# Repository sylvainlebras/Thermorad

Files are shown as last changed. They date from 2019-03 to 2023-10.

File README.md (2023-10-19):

# Thermorad
Intuitive EMC tool with visual feedback
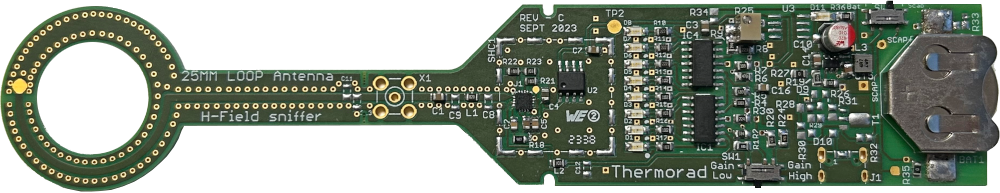
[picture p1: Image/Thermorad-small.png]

This tool is meant to be used for EMC investigation and EMC teaching, it provides a simple and quick feedback through an 8 LED indicator.

Possible use includes : 
- Locating near H-field emission sources 
- Locating near E-field emission sources (requires E Field antenna)
- Demonstrating polarisation of emitters-receivers
- Locating wifi and 4G/5G antennas on a phone
- Evaluation of perturbations carried by a cable (requires ferrite clamp)

Coming next
- Version D with Geiger like sound output
- E-Field antenna
- Small diameter H Field antenna

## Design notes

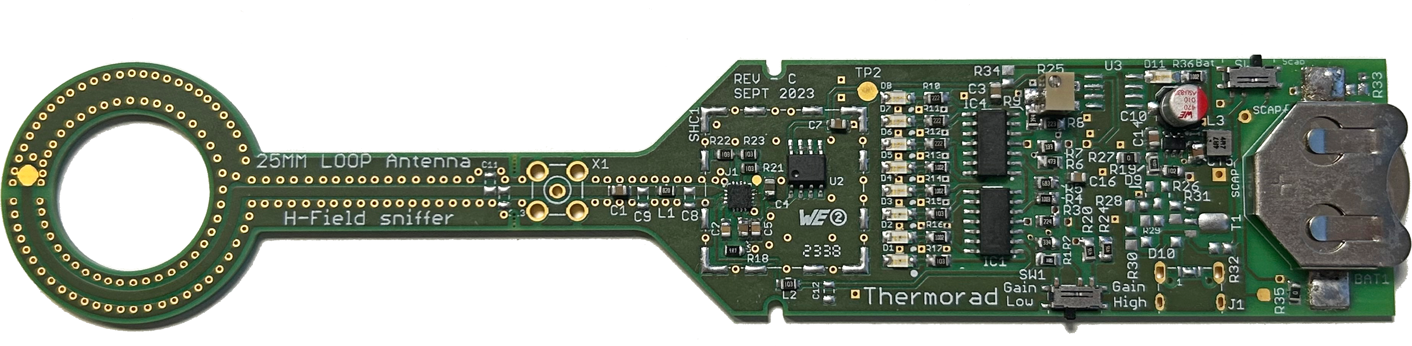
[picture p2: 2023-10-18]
Image/Thermorad-C.png

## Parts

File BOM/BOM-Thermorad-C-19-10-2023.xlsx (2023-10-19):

Parts | Qty | Value | Device | Package | Description | Manufacturer
C2, C5 | 2 | 0805/100nF/16V | 885012207045 | WCAP-CSGP_0805_REFLOW | WCAP-CSGP Ceramic Capacitors | Wurth-Elektronik / Generic
C14, C15 | 2 | 0805/10µF/10V | 885012207026 | C0805 | CAPACITOR, European symbol | Wurth-Elektronik / Generic
C7, C16 | 2 | 0805/1µF/10V | 885012207051 | WCAP-CSGP_0805_REFLOW | WCAP-CSGP Ceramic Capacitors | Wurth-Elektronik / Generic
C6 | 1 | 0805/1µF/16V | 885012207051 | WCAP-CSGP_0805_REFLOW | WCAP-CSGP Ceramic Capacitors | Wurth-Elektronik / Generic
C3 | 1 | 0805/2.2µF/10V | 885012207024 | WCAP-CSGP_0805_REFLOW | WCAP-CSGP Ceramic Capacitors | Wurth-Elektronik / Generic
C4 | 1 | 0805/22µF/10V | 885012107011 | WCAP-CSGP_0805_REFLOW | WCAP-CSGP Ceramic Capacitors | Wurth-Elektronik / Generic
R27, R35 | 2 | 0R | R-EU_R0805 | R0805 | RESISTOR, European symbol | Generic
R4 | 1 | 100k | R-EU_M0805 | M0805 | RESISTOR, European symbol | Generic
R25 | 1 | 100k/TC33X-2-104G | R-TRIMM3224X | RTRIM3224X | Trimm resistor | Bourns / Generic
C10 | 1 | 100µF/6.3V/865080142007 | WCAP-ASLI_5X5.5(DXL) | 3X1.6X1.4(BXCXA) | WCAP-ASLI Aluminum Electrolytic Capacitors | Wurth-Elektronik
R32 | 1 | 10R/DNP | R-EU_R0805 | R0805 | RESISTOR, European symbol
R13, R14, R15, R16, R17, R21, R22, R23, R36 | 9 | 10k | R-EU_M0805 | M0805 | RESISTOR, European symbol | Generic
R28 | 1 | 10k/DNP | R-EU_R0805 | R0805 | RESISTOR, European symbol
D2, D3 | 2 | 150120AS75000 | WL-SMCW-150120GS75000-G | 1206 | SMD mono-color Chip LED | Wurth-Elektronik
D6, D7, D8, D11 | 4 | 150120BS75000 | WL-SMCW-150120GS75000-G | 1206 | SMD mono-color Chip LED | Wurth-Elektronik
D4, D5 | 2 | 150120GS75000 | WL-SMCW-150120GS75000-G | 1206 | SMD mono-color Chip LED | Wurth-Elektronik
D1 | 1 | 150120RS75000 | WL-SMCW-150120GS75000-G | 1206 | SMD mono-color Chip LED | Wurth-Elektronik
R31 | 1 | 1K/DNP | R-EU_R0805 | R0805 | RESISTOR, European symbol
R1 | 1 | 1M8 | R-EU_M0805 | M0805 | RESISTOR, European symbol | Generic
R26 | 1 | 1k | R-EU_R0805 | R0805 | RESISTOR, European symbol | Generic
R3 | 1 | 220k | R-EU_M0805 | M0805 | RESISTOR, European symbol | Generic
R29 | 1 | 22R/DNP | R-EU_R0805 | R0805 | RESISTOR, European symbol
R8 | 1 | 22k | R-EU_M0805 | M0805 | RESISTOR, European symbol | Generic
R10, R11, R12 | 3 | 2k2 | R-EU_M0805 | M0805 | RESISTOR, European symbol | Generic
L3 | 1 | 74438336047 | WE-MAPI_3015/3020 | WE-MAPI_3015/3020 | SMD Metal Alloy Power Inductor | Wurth-Elektronik
R2 | 1 | 330k | R-EU_M0805 | M0805 | RESISTOR, European symbol | Generic
R7 | 1 | 33k | R-EU_M0805 | M0805 | RESISTOR, European symbol | Generic
R9 | 1 | 390k | R-EU_M0805 | M0805 | RESISTOR, European symbol | Generic
SW1, SW2 | 2 | 450404015514 | 450404015514 | 450404015514 | WS-SLSU | Wurth-Elektronik
R6 | 1 | 47k | R-EU_M0805 | M0805 | RESISTOR, European symbol | Generic
R20, R24 | 2 | 4M7 | R-EU_M0805 | M0805 | RESISTOR, European symbol | Generic
R18 | 1 | 4R7 | R-EU_M0805 | M0805 | RESISTOR, European symbol | Generic
R30 | 1 | 680/DNP | R-EU_R0805 | R0805 | RESISTOR, European symbol
R5 | 1 | 68k | R-EU_M0805 | M0805 | RESISTOR, European symbol | Generic
BAT1 | 1 | 79523141 | WA-BCMC_SMT_79523141 | 79523141 | Battery Holder WA-BCMC | Wurth-Elektronik
BAT2 | 1 | 79523141/DNP | WA-BCMC_SMT_79523141 | 79523141 | Battery Holder WA-BCMC
R19 | 1 | 9.1k | R-EU_R0805 | R0805 | RESISTOR, European symbol | Generic
U1 | 1 | ADL5910 | ADL5910 | LFCSP-16 |  | Analog Devices
C1 | 1 | 0805/1µF | 885012207051 | WCAP-CSGP_0805_REFLOW | WCAP-CSGP Ceramic Capacitors | Wurth-Elektronik / Generic
J1 | 1 | DNP | 629105150521 | 629105150521 | WR-COM_USB_Micro Type B_Horizontal_SMT ;
T1 | 1 | DNP | BF622-NPN-SOT89-BCE | SOT89-BCE | NPN Transistror
D10 | 1 | DNP | DIODE-SOD123 | SOD123 | DIODE
R33, R34 | 2 | DNP | R-EU_R0805 | R0805 | RESISTOR, European symbol
C8, C12 | 2 | DNP | WCAP-CSGP_0805-REFLOW | WCAP-CSGP_0805_REFLOW | WCAP-CSGP Ceramic Capacitors
C9 | 1 | DNP/!RES/0805/82R | WCAP-CSGP_0805-REFLOW | WCAP-CSGP_0805_REFLOW | WCAP-CSGP Ceramic Capacitors
C11, C13 | 2 | DNP/1N4148 | WCAP-CSGP_0805-REFLOW | WCAP-CSGP_0805_REFLOW | WCAP-CSGP Ceramic Capacitors
SHC1 | 1 | DNP/36103205S | WE-SHC_36103205S | WE-SHC_36103205S | Shielding Cabinet
X1 | 1 | DNP/BU-SMA-V | BU-SMA-V | BU-SMA-V | FEMALE SMA CONNECTOR
U2 | 1 | LM2936M-3.3 | LM2936M-3.3 | SO08 | Ultra-Low Quiescent Current LDO Voltage Regulator | Texas Instruments
U3 | 1 | LM2936M-5.0/DNP | LM2936M-5.0 | SO08 | Ultra-Low Quiescent Current LDO Voltage Regulator
IC1, IC4 | 2 | LM324D | Many more like AD8644R | SO14 | Single and Quad 18 V Operational Amplifiers | Generic
D9 | 1 | LM431-SACM3X/DNP | LM431-SACM3X | SOT23
L2 | 1 | RES/0805/10k |  | 805 | WE-CBF SMD EMI Suppression Ferrite Bead | Generic
L1 | 1 | RES/0805/82R/5% |  | 805 | SMD Wire Wound Ceramic Inductor | Generic
SCAP2 | 1 | TESTPOINT-GROS | TESTPOINT-GROS | TESTPOINT-GROS
TP3 | 1 | TPB1,27 | TPB1,27 | B1,27 | Test pad
TP1, TP2 | 2 | TPB2,54 | TPB2,54 | B2,54 | Test pad
IC2 | 1 | TPS61070DDC | TPS61070DDC | TSOT23-6_DDC | 90% EFFICIENT SYNCHRONOUS BOOST CONVERTER WITH 600-mA SWITCH | Texas Instruments

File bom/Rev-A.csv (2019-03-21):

Part | Value | Device | Package | Description
BAT1 | 79523141 | WA-BCMC_SMT_79523141 | 79523141 | Battery Holder WA-BCMC
BAT2 | 79523141 | WA-BCMC_SMT_79523141 | 79523141 | Battery Holder WA-BCMC
C1 |  | WCAP-CSGP_0805-REFLOW | WCAP-CSGP_0805_REFLOW | WCAP-CSGP Ceramic Capacitors
C2 |  | WCAP-CSGP_0805-REFLOW | WCAP-CSGP_0805_REFLOW | WCAP-CSGP Ceramic Capacitors
C3 |  | WCAP-CSGP_0805-REFLOW | WCAP-CSGP_0805_REFLOW | WCAP-CSGP Ceramic Capacitors
C4 |  | WCAP-CSGP_0805-REFLOW | WCAP-CSGP_0805_REFLOW | WCAP-CSGP Ceramic Capacitors
C5 |  | WCAP-CSGP_0805-REFLOW | WCAP-CSGP_0805_REFLOW | WCAP-CSGP Ceramic Capacitors
C6 |  | WCAP-CSGP_0805-REFLOW | WCAP-CSGP_0805_REFLOW | WCAP-CSGP Ceramic Capacitors
C7 |  | WCAP-CSGP_0805-REFLOW | WCAP-CSGP_0805_REFLOW | WCAP-CSGP Ceramic Capacitors
C8 |  | WCAP-CSGP_0805-REFLOW | WCAP-CSGP_0805_REFLOW | WCAP-CSGP Ceramic Capacitors
C9 |  | WCAP-CSGP_0805-REFLOW | WCAP-CSGP_0805_REFLOW | WCAP-CSGP Ceramic Capacitors
C10 |  | WCAP-ASLI_5X5.5(DXL) | 3X1.6X1.4(BXCXA) | WCAP-ASLI Aluminum Electrolytic Capacitors
C11 |  | WCAP-CSGP_0805-REFLOW | WCAP-CSGP_0805_REFLOW | WCAP-CSGP Ceramic Capacitors
C12 |  | WCAP-CSGP_0805-REFLOW | WCAP-CSGP_0805_REFLOW | WCAP-CSGP Ceramic Capacitors
C13 |  | WCAP-CSGP_0805-REFLOW | WCAP-CSGP_0805_REFLOW | WCAP-CSGP Ceramic Capacitors
D1 | 150120GS75000 | WL-SMCW-150120GS75000-G | 1206 | SMD mono-color Chip LED
D2 | 150120GS75000 | WL-SMCW-150120GS75000-G | 1206 | SMD mono-color Chip LED
D3 | 150120GS75000 | WL-SMCW-150120GS75000-G | 1206 | SMD mono-color Chip LED
D4 | 150120GS75000 | WL-SMCW-150120GS75000-G | 1206 | SMD mono-color Chip LED
D5 | 150120GS75000 | WL-SMCW-150120GS75000-G | 1206 | SMD mono-color Chip LED
D6 | 150120GS75000 | WL-SMCW-150120GS75000-G | 1206 | SMD mono-color Chip LED
D7 | 150120GS75000 | WL-SMCW-150120GS75000-G | 1206 | SMD mono-color Chip LED
D8 | 150120GS75000 | WL-SMCW-150120GS75000-G | 1206 | SMD mono-color Chip LED
IC1 | AD8644R | AD8644R | SO14 | Single and Quad 18 V Operational Amplifiers
IC4 | AD8644R | AD8644R | SO14 | Single and Quad 18 V Operational Amplifiers
L1 |  | WE-KI_0805A | WE-KI_0805A | SMD Wire Wound Ceramic Inductor
L2 |  | WE-CBF_0805_74279209_WB_HS | WE-CBF_0805(W=3.0) | WE-CBF SMD EMI Suppression Ferrite Bead
R1 | 3M3 | R-EU_M0805 | M0805 | RESISTOR, European symbol
R2 | TBD | R-EU_M0805 | M0805 | RESISTOR, European symbol
R3 | TBD | R-EU_M0805 | M0805 | RESISTOR, European symbol
R4 | TBD | R-EU_M0805 | M0805 | RESISTOR, European symbol
R5 | TBD | R-EU_M0805 | M0805 | RESISTOR, European symbol
R6 | TBD | R-EU_M0805 | M0805 | RESISTOR, European symbol
R7 | TBD | R-EU_M0805 | M0805 | RESISTOR, European symbol
R8 | TBD | R-EU_M0805 | M0805 | RESISTOR, European symbol
R9 | 47k | R-EU_M0805 | M0805 | RESISTOR, European symbol
R10 | 10k | R-EU_M0805 | M0805 | RESISTOR, European symbol
R11 | 10k | R-EU_M0805 | M0805 | RESISTOR, European symbol
R12 | 10k | R-EU_M0805 | M0805 | RESISTOR, European symbol
R13 | 10k | R-EU_M0805 | M0805 | RESISTOR, European symbol
R14 | 10k | R-EU_M0805 | M0805 | RESISTOR, European symbol
R15 | 10k | R-EU_M0805 | M0805 | RESISTOR, European symbol
R16 | 10k | R-EU_M0805 | M0805 | RESISTOR, European symbol
R17 | 10k | R-EU_M0805 | M0805 | RESISTOR, European symbol
R18 |  | R-EU_R0603 | R0603 | RESISTOR, European symbol
R19 | 100k | POTENTIOMETER_PT_SPIN | PT-SPIN | Potentiometer
R20 |  | R-EU_M0805 | M0805 | RESISTOR, European symbol
R21 |  | R-EU_R0603 | R0603 | RESISTOR, European symbol
R22 |  | R-EU_R0603 | R0603 | RESISTOR, European symbol
R23 |  | R-EU_R0603 | R0603 | RESISTOR, European symbol
SHC1 | 36103205S | WE-SHC_36103205S | WE-SHC_36103205S | Shielding Cabinet
SW1 | 450404015514 | 450404015514 | 450404015514 | WS-SLSU
SW2 | 450404015514 | 450404015514 | 450404015514 | WS-SLSU
TP1 | TPB2,54 | TPB2,54 | B2,54 | Test pad
TP2 | TPB2,54 | TPB2,54 | B2,54 | Test pad
TP3 | TPB1,27 | TPB1,27 | B1,27 | Test pad
U1 | ADL5910 | ADL5910 | LFCSP-16
U2 | LM2936M-3.3 | LM2936M-3.3 | SO08 | Ultra-Low Quiescent Current LDO Voltage Regulator
U3 | LM2936M-5.0 | LM2936M-5.0 | SO08 | Ultra-Low Quiescent Current LDO Voltage Regulator
X1 | BU-SMA-V | BU-SMA-V | BU-SMA-V | FEMALE SMA CONNECTOR

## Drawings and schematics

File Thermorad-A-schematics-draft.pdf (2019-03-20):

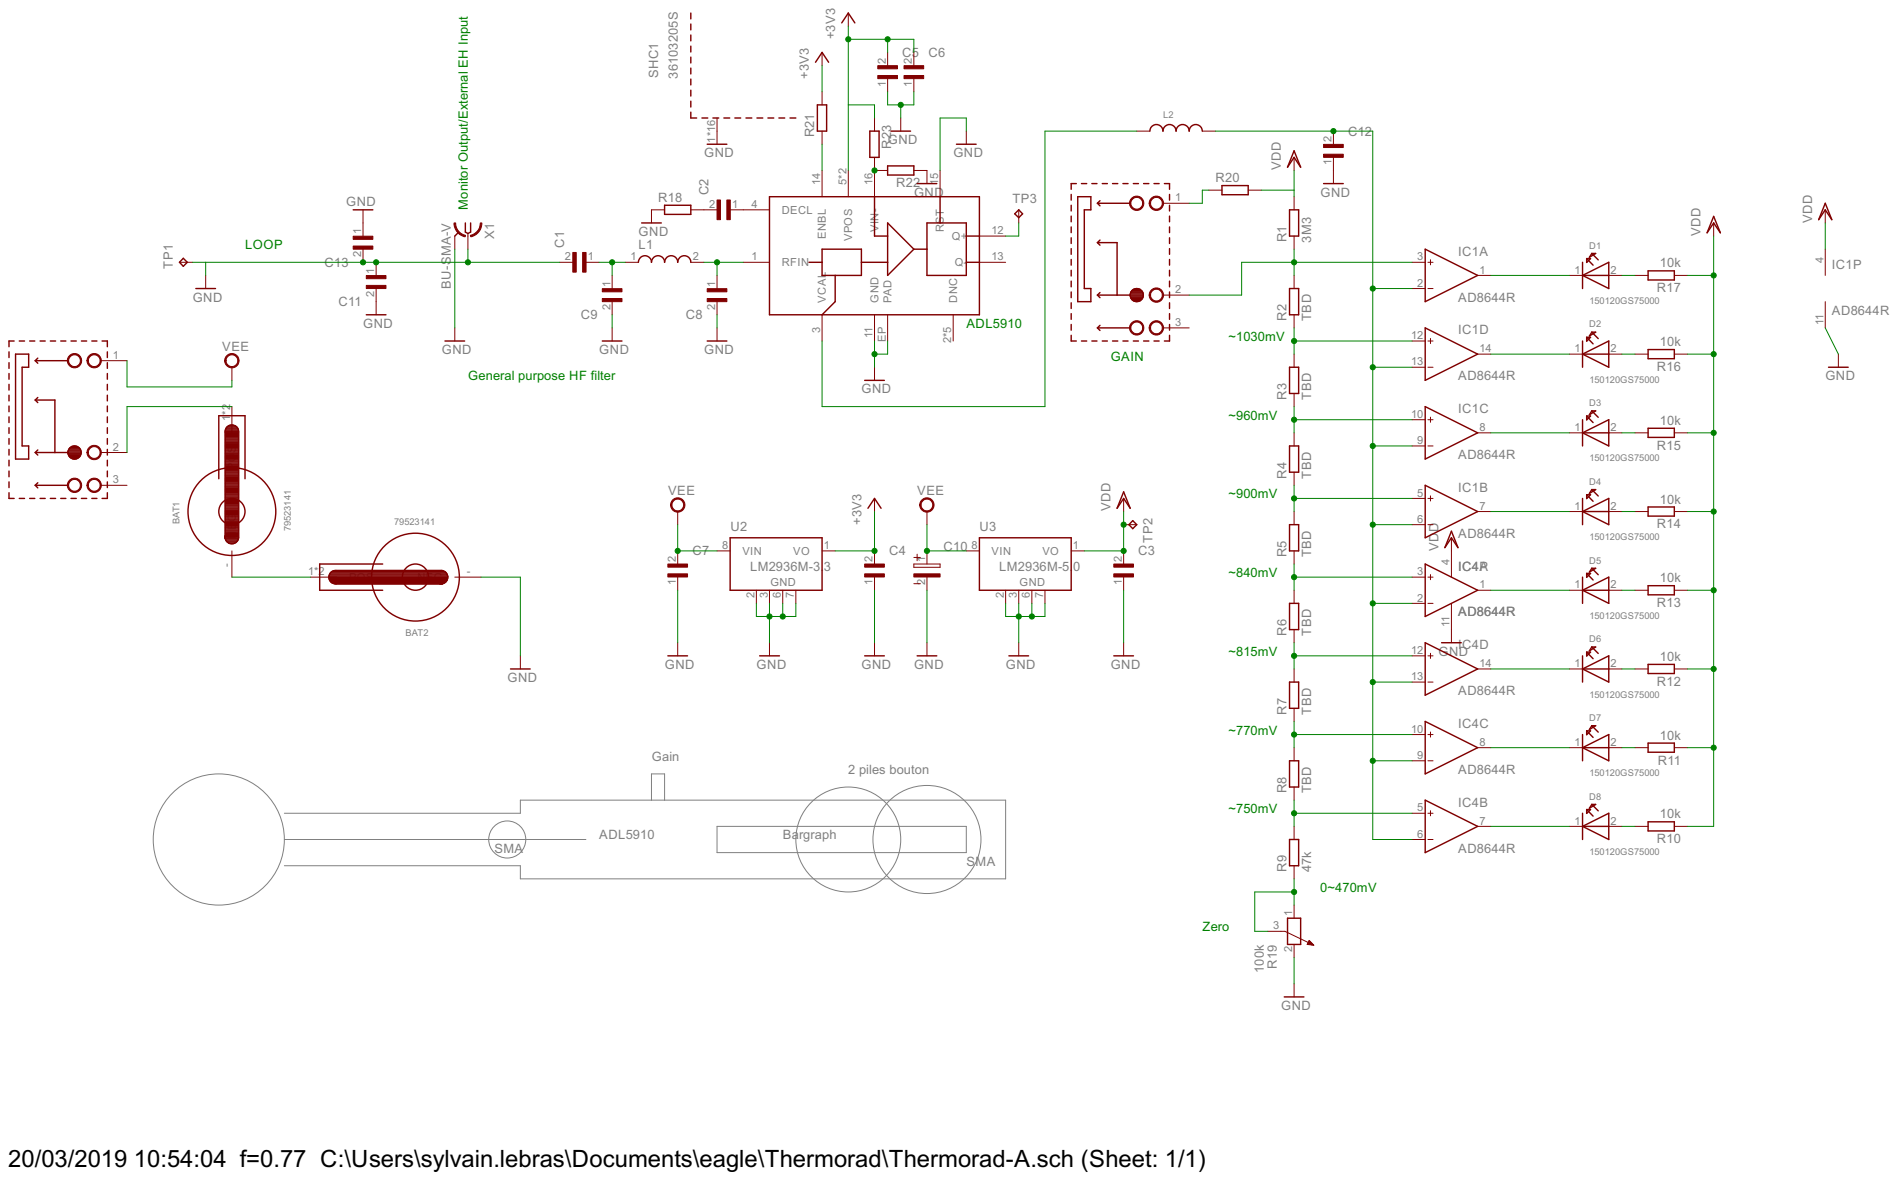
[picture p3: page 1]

Monitor Output/External EH Input

3M3 TBD TBD TBD TBD TBD TBD TBD 47k GND

General purpose HF filter

2 piles bouton Bargraph Gain

20/03/2019 10:54:04 f=0.77 C:\Users\sylvain.lebras\Documents\eagle\Thermorad\Thermorad-A.sch (Sheet: 1/1)

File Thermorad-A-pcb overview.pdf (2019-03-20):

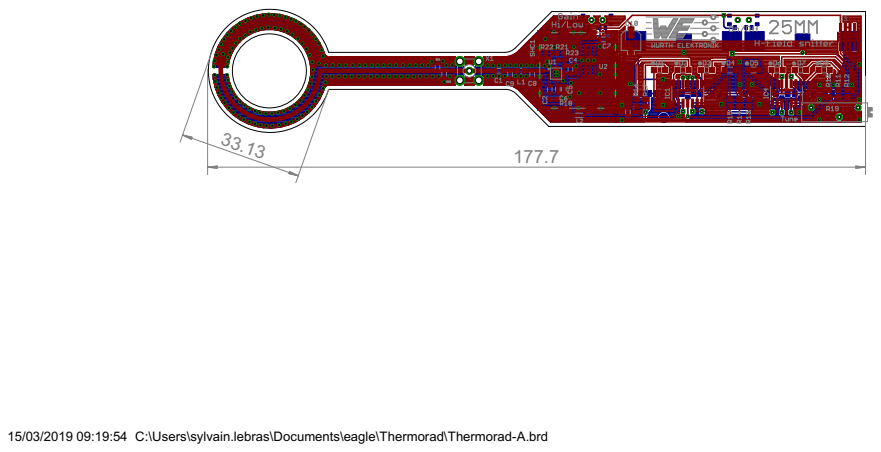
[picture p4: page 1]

15/03/2019 09:19:54 C:\Users\sylvain.lebras\Documents\eagle\Thermorad\Thermorad-A.brd

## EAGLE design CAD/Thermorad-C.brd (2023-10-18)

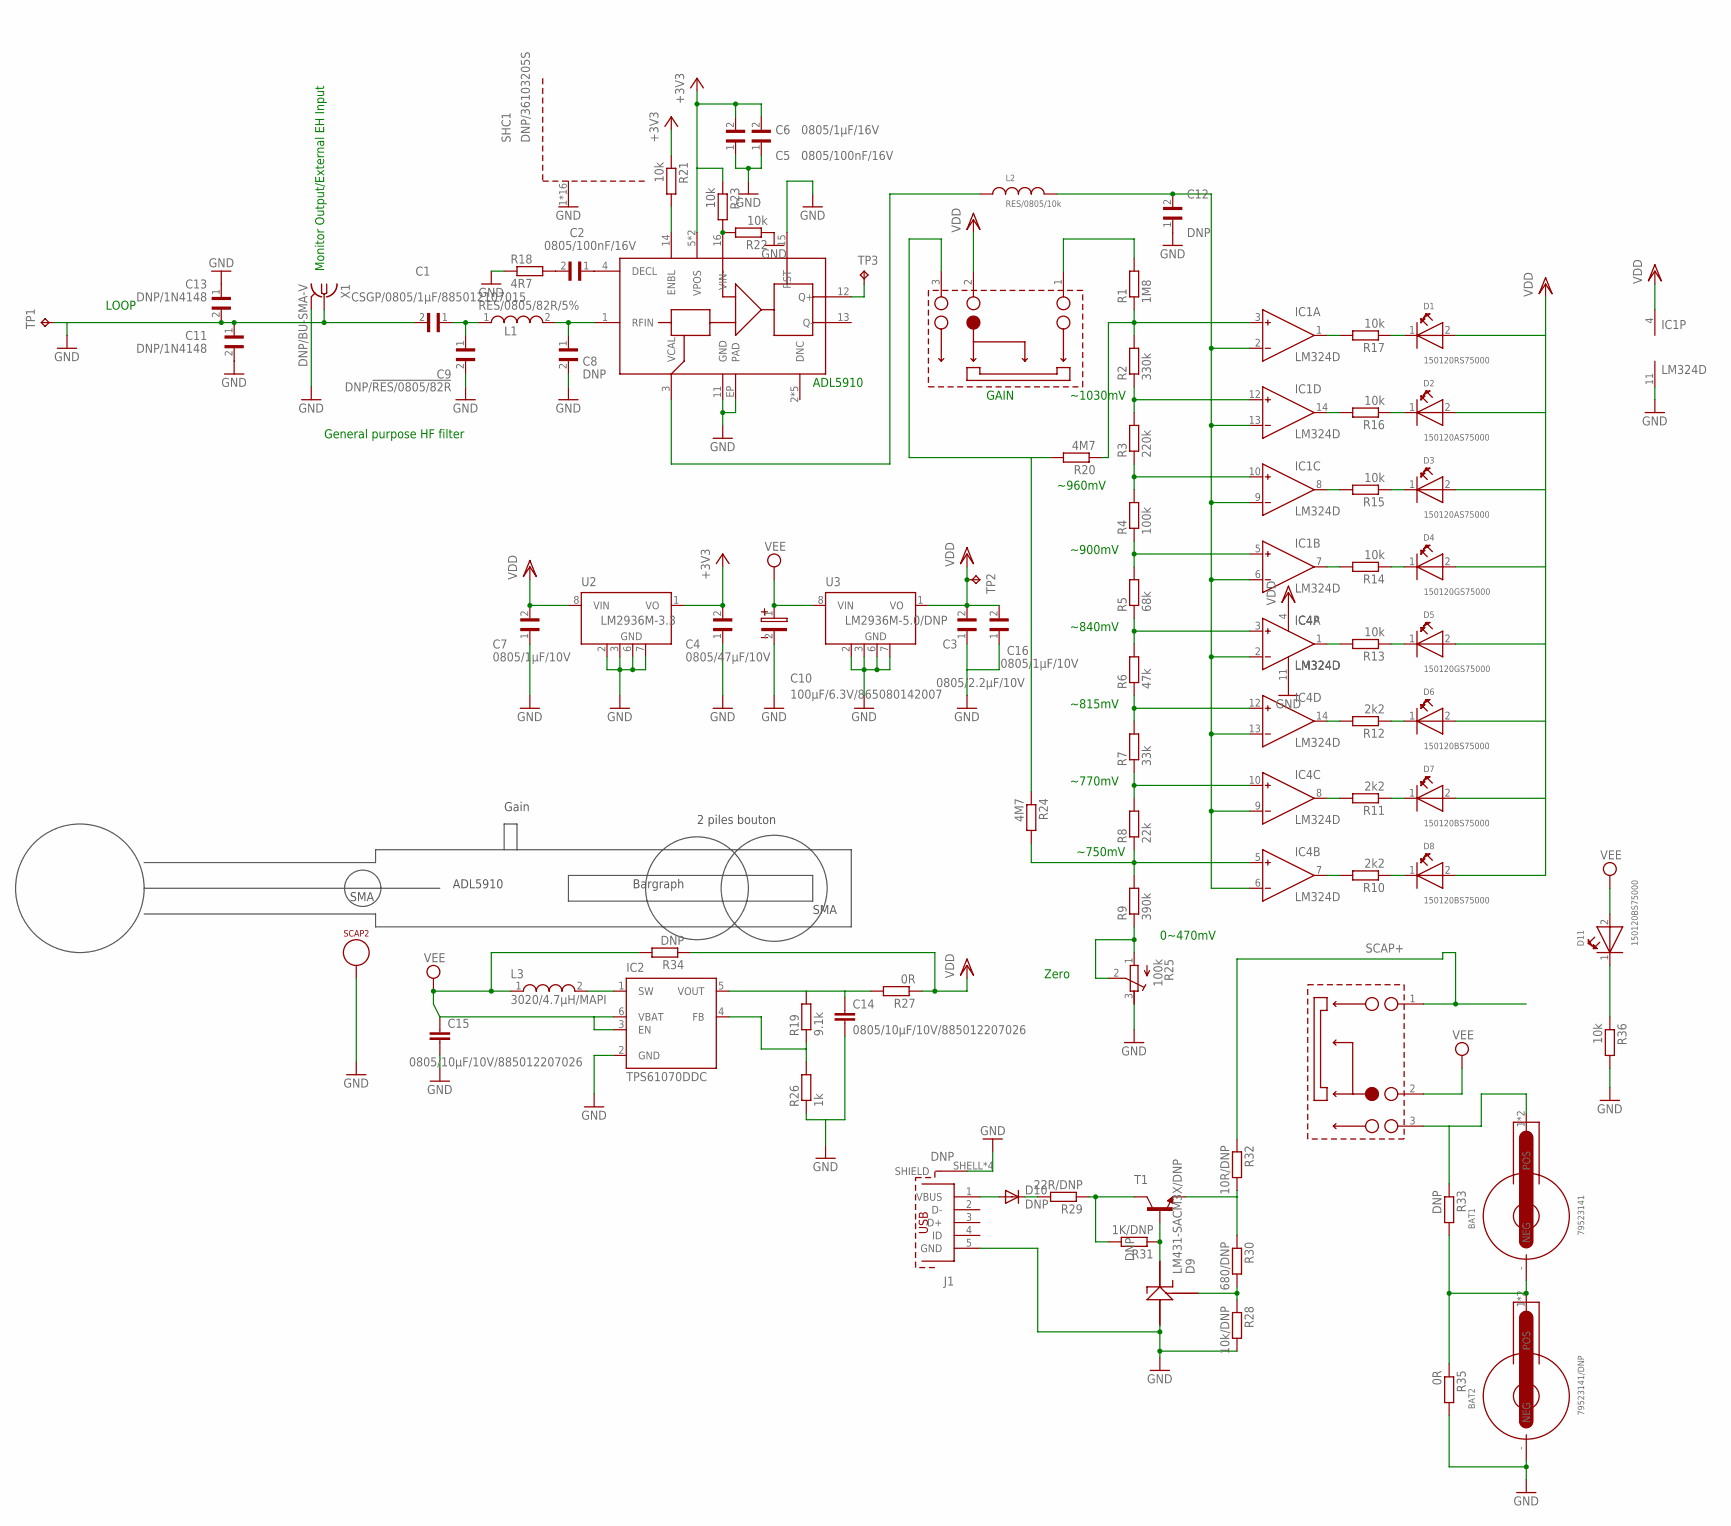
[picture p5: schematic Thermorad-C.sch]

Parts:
BAT1: 79523141
BAT2: 79523141/DNP; 79523141
C1: CSGP/0805/1µF/885012107015; WCAP-CSGP_0805_REFLOW
C2, C5: 0805/100nF/16V; WCAP-CSGP_0805_REFLOW
C3: 0805/2.2µF/10V; WCAP-CSGP_0805_REFLOW
C4: 0805/47µF/10V; WCAP-CSGP_0805_REFLOW
C6: 0805/1µF/16V; WCAP-CSGP_0805_REFLOW
C7, C16: 0805/1µF/10V; WCAP-CSGP_0805_REFLOW
C8, C12: DNP; WCAP-CSGP_0805_REFLOW
C9: DNP/!RES/0805/82R; WCAP-CSGP_0805_REFLOW
C10: 100µF/6.3V/865080142007; 3X1.6X1.4(BXCXA)
C11, C13: DNP/1N4148; WCAP-CSGP_0805_REFLOW
C14, C15: 0805/10µF/10V/885012207026; C0805
D1: 150120RS75000; 1206
D2, D3: 150120AS75000; 1206
D4, D5: 150120GS75000; 1206
D6, D7, D8, D11: 150120BS75000; 1206
D9: LM431-SACM3X/DNP; SOT23
D10: DNP; SOD123
IC1: LM324D; SO14; MPN AD8644ARZ
IC2: TPS61070DDC; TSOT23-6_DDC
IC4: LM324D; SO14
J1: DNP; 629105150521
L1: RES/0805/82R/5%; WE-KI_0805A
L2: RES/0805/10k; WE-CBF_0805(W=3.0)
L3: 3020/4.7µH/MAPI; WE-MAPI_3015/3020
R1: 1M8; M0805
R2: 330k; M0805
R3: 220k; M0805
R4: 100k; M0805
R5: 68k; M0805
R6: 47k; M0805
R7: 33k; M0805
R8: 22k; M0805
R9: 390k; M0805
R10, R11, R12: 2k2; M0805
R13, R14, R15, R16, R17, R21, R22, R23, R36: 10k; M0805
R18: 4R7; M0805
R19: 9.1k; R0805
R20, R24: 4M7; M0805
R25: 100k; RTRIM3224X
R26: 1k; R0805
R27, R35: 0R; R0805
R28: 10k/DNP; R0805
R29: 22R/DNP; R0805
R30: 680/DNP; R0805
R31: 1K/DNP; R0805
R32: 10R/DNP; R0805
R33, R34: DNP; R0805
SCAP2: TESTPOINT-GROS
SHC1: DNP/36103205S; WE-SHC_36103205S
SW1, SW2: 450404015514
T1: DNP; SOT89-BCE
TP1, TP2: TPB2,54; B2,54
TP3: TPB1,27; B1,27
U1: ADL5910; LFCSP-16
U2: LM2936M-3.3; SO08
U3: LM2936M-5.0/DNP; SO08
X1: DNP/BU-SMA-V; BU-SMA-V

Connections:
+3V3: C4.2, C5.2, C6.2, R21.1, R23.1, U1.5 (VPOS), U1.7 (VPOS), U2.1 (VO)
GND: BAT2.- (NEG), C1.2, C3.1, C4.1, C5.1, C6.1, C7.1, C8.2, C9.2, C10.2, C11.1, C11.2, C12.1, C13.1, C13.2, C14.2, C15.2, C16.1, D9.3 (A), IC1.11 (V-), IC2.2 (GND), IC4.11 (V-), J1.5 (GND), J1.SHELL (SHIELD), J1.SHELL1 (SHIELD), J1.SHELL2 (SHIELD), J1.SHELL3 (SHIELD), R18.1, R22.1, R25.3 (A), R26.1, R28.2, R35.2, R36.2, SCAP2.1, SHC1.1, SHC1.2, SHC1.3, SHC1.4, SHC1.5, SHC1.6, SHC1.7, SHC1.8, SHC1.9, SHC1.10, SHC1.11, SHC1.12, SHC1.13, SHC1.14, SHC1.15, SHC1.16, TP1.TP, U1.11 (GND), U1.15 (RST), U1.EP (PAD), U2.2 (GND), U2.3 (GND), U2.6 (GND), U2.7 (GND), U3.2 (GND), U3.3 (GND), U3.6 (GND), U3.7 (GND), X1.1, X1.2 (GND), X1.3 (GND), X1.4 (GND), X1.5 (GND)
unnamed: IC2.1 (SW), L3.2
unnamed: IC4.10 (IN+), R7.1, R8.2
unnamed: IC4.12 (IN+), R6.1, R7.2
unnamed: IC4.3 (IN+), R5.1, R6.2
unnamed: IC1.5 (IN+), R4.1, R5.2
unnamed: IC1.10 (IN+), R3.1, R4.2
unnamed: IC1.12 (IN+), R2.1, R3.2
unnamed: IC1.3 (IN+), R1.1, R2.2, R20.1
unnamed: C1.1, C9.1, L1.1
unnamed: IC4.14 (OUT), R12.2
unnamed: C8.1, L1.2, U1.1 (RFIN)
unnamed: IC1.1 (OUT), R17.2
unnamed: D1.1 (K), R17.1
unnamed: IC1.14 (OUT), R16.2
unnamed: D6.1 (K), R12.1
unnamed: IC4.8 (OUT), R11.2
unnamed: D7.1 (K), R11.1
unnamed: D2.1 (K), R16.1
unnamed: IC1.8 (OUT), R15.2
unnamed: IC4.7 (OUT), R10.2
unnamed: D8.1 (K), R10.1
unnamed: D3.1 (K), R15.1
unnamed: IC1.7 (OUT), R14.2
unnamed: D4.1 (K), R14.1
unnamed: IC4.1 (OUT), R13.2
unnamed: D5.1 (K), R13.1
unnamed: BAT1.1 (POS), BAT1.2 (POS), R33.1, SW2.3
unnamed: BAT1.- (NEG), BAT2.1 (POS), BAT2.2 (POS), R33.2, R35.1
unnamed: R1.2, SW1.1
unnamed: C2.1, U1.4 (DECL)
unnamed: C2.2, R18.2
unnamed: C12.2, IC1.2 (IN-), IC1.6 (IN-), IC1.9 (IN-), IC1.13 (IN-), IC4.2 (IN-), IC4.6 (IN-), IC4.9 (IN-), IC4.13 (IN-), L2.2
unnamed: R9.1, R25.1 (E), R25.2 (S)
unnamed: L2.1, U1.3 (VCAL)
unnamed: R21.2, U1.14 (ENBL)
unnamed: R20.2, R24.1, SW1.3
unnamed: R22.2, R23.2, U1.16 (VIN-)
unnamed: R30.1, R32.2, T1.E
unnamed: TP3.TP, U1.12 (Q+)
unnamed: IC4.5 (IN+), R8.1, R9.2, R24.2
unnamed: IC2.4 (FB), R19.1, R26.2
unnamed: C14.1, IC2.5 (VOUT), R19.2, R27.2
unnamed: D11.1 (K), R36.1
unnamed: D10.A, J1.1 (VBUS)
unnamed: D10.C, R29.2
unnamed: R29.1, R31.2, T1.C
unnamed: D9.1 (K), R31.1, T1.B
unnamed: D9.2 (REF), R28.1, R30.2
SCAP+: R32.1, SW2.1
VDD: C3.2, C7.2, C16.2, D1.2 (A), D2.2 (A), D3.2 (A), D4.2 (A), D5.2 (A), D6.2 (A), D7.2 (A), D8.2 (A), IC1.4 (V+), IC4.4 (V+), R27.1, R34.1, SW1.2, TP2.TP, U2.8 (VIN), U3.1 (VO)
VEE: C10.1, C15.1, D11.2 (A), IC2.3 (EN), IC2.6 (VBAT), L3.1, R34.2, SW2.2, U3.8 (VIN)

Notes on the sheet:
ADL5910
SMA
2 piles bouton
Bargraph
Gain
~750mV
0~470mV
Zero
GAIN
~770mV
~815mV
~840mV
~900mV
~960mV
~1030mV
LOOP
General purpose HF filter
Monitor Output/External EH Input

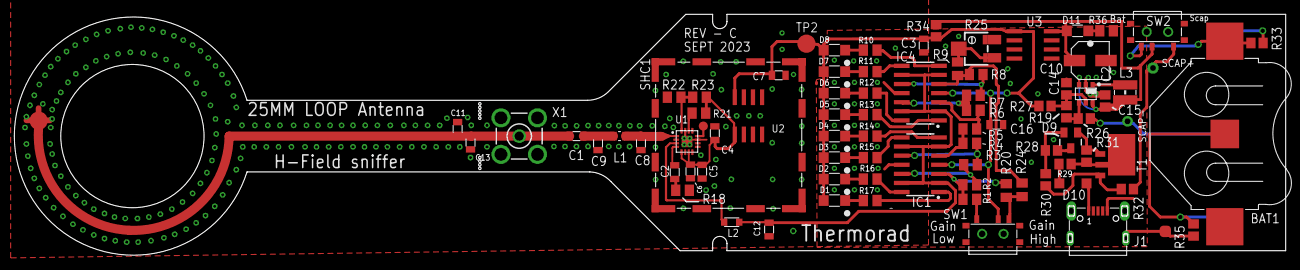
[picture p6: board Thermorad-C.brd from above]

Board: 2 copper layers, 177.5 x 33.6 mm, 84 parts (1 on the bottom side), 53 nets.

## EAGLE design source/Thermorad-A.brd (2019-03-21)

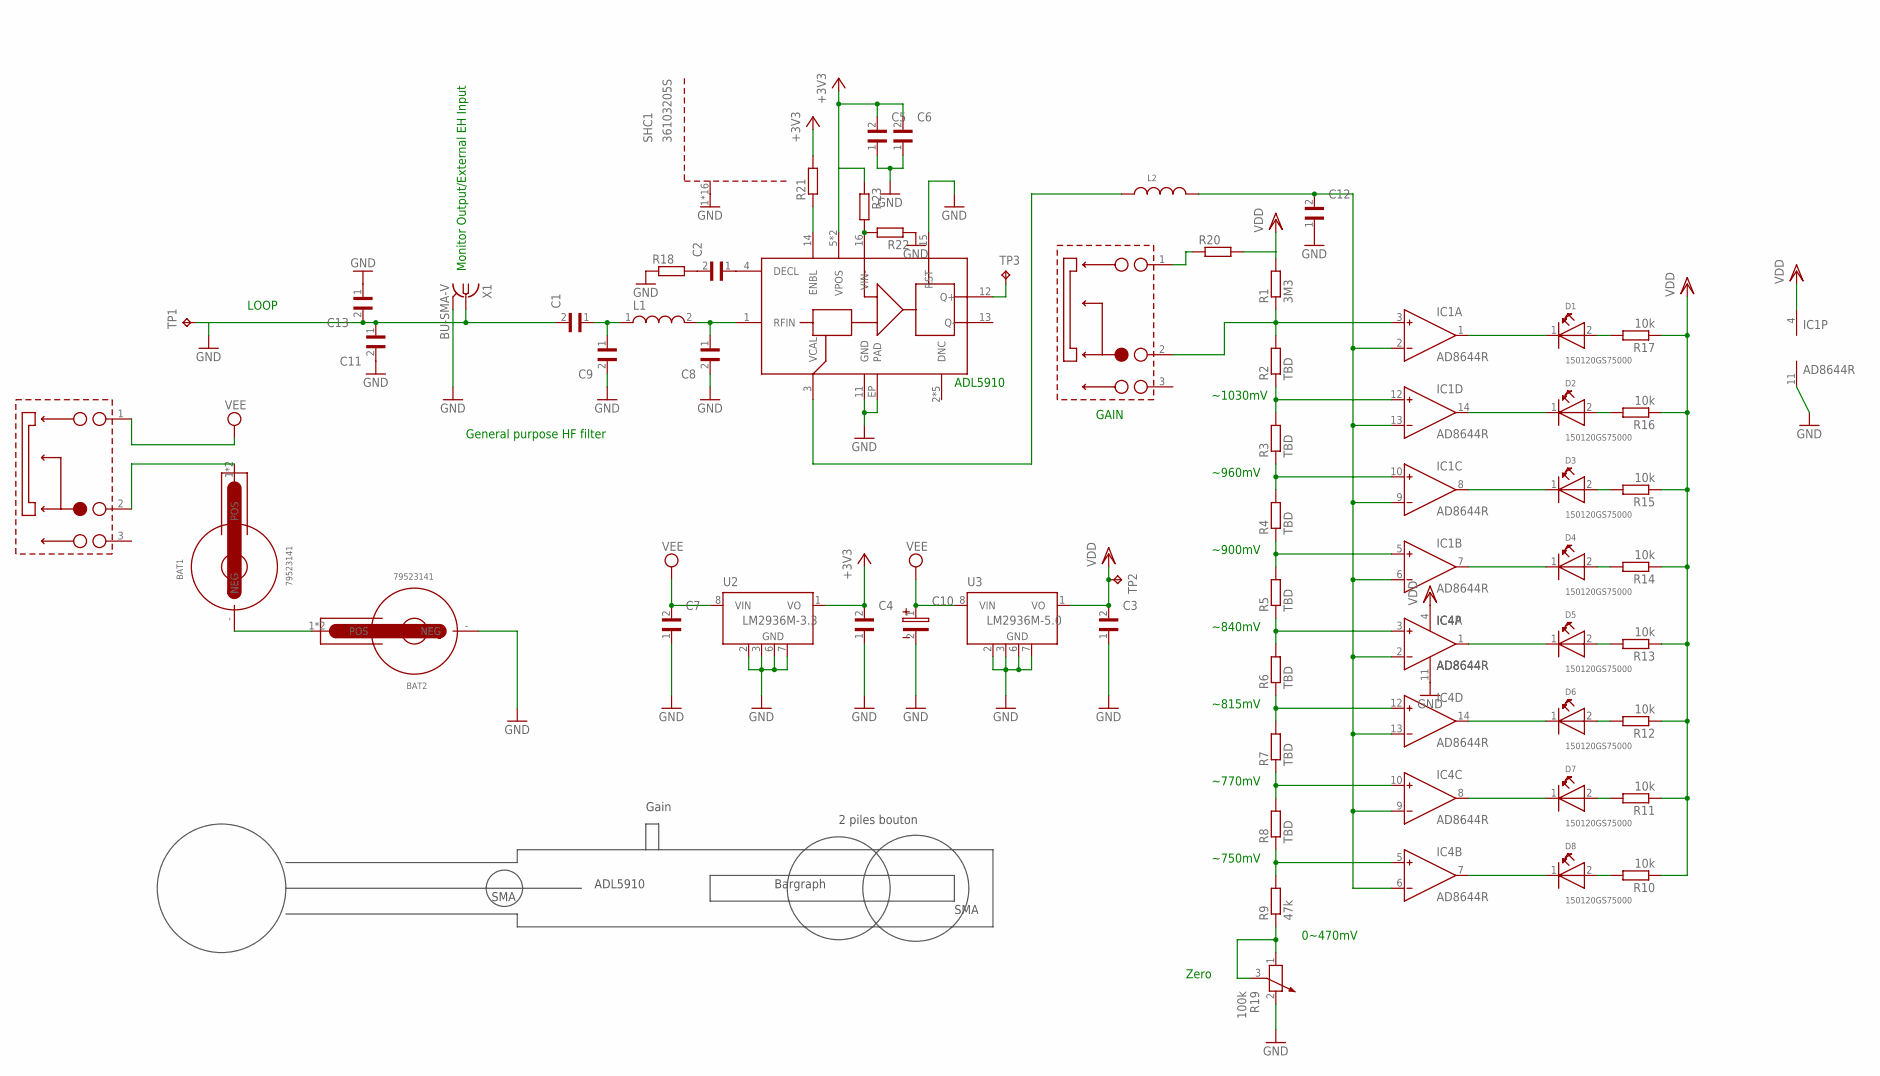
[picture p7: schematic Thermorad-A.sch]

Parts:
BAT1, BAT2: 79523141
C1, C2, C3, C4, C5, C6, C7, C8, C9, C11, C12, C13: WCAP-CSGP_0805-REFLOW; WCAP-CSGP_0805_REFLOW
C10: WCAP-ASLI_5X5.5(DXL); 3X1.6X1.4(BXCXA)
D1, D2, D3, D4, D5, D6, D7, D8: 150120GS75000; 1206
IC1: AD8644R; SO14; MPN AD8644ARZ
IC4: AD8644R; SO14
L1: WE-KI_0805A
L2: WE-CBF_0805_74279209_WB_HS; WE-CBF_0805(W=3.0)
R1: 3M3; M0805
R2, R3, R4, R5, R6, R7, R8: TBD; M0805
R9: 47k; M0805
R10, R11, R12, R13, R14, R15, R16, R17: 10k; M0805
R18, R21, R22, R23: R-EU_R0603; R0603
R19: 100k; PT-SPIN
R20: R-EU_M0805; M0805
SHC1: 36103205S; WE-SHC_36103205S
SW1, SW2: 450404015514
TP1, TP2: TPB2,54; B2,54
TP3: TPB1,27; B1,27
U1: ADL5910; LFCSP-16
U2: LM2936M-3.3; SO08
U3: LM2936M-5.0; SO08
X1: BU-SMA-V

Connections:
+3V3: C4.2, C5.2, C6.2, R21.2, R23.1, U1.5 (VPOS), U1.7 (VPOS), U2.1 (VO)
GND: BAT2.- (NEG), C1.2, C3.1, C4.1, C5.1, C6.1, C7.1, C8.2, C9.2, C10.2, C11.1, C11.2, C12.1, C13.1, C13.2, IC1.11 (V-), IC4.11 (V-), R18.1, R19.2, R22.1, SHC1.1, SHC1.2, SHC1.3, SHC1.4, SHC1.5, SHC1.6, SHC1.7, SHC1.8, SHC1.9, SHC1.10, SHC1.11, SHC1.12, SHC1.13, SHC1.14, SHC1.15, SHC1.16, TP1.TP, U1.11 (GND), U1.15 (RST), U1.EP (PAD), U2.2 (GND), U2.3 (GND), U2.6 (GND), U2.7 (GND), U3.2 (GND), U3.3 (GND), U3.6 (GND), U3.7 (GND), X1.1, X1.2 (GND), X1.3 (GND), X1.4 (GND), X1.5 (GND)
unnamed: IC4.5 (IN+), R8.1, R9.2
unnamed: IC4.10 (IN+), R7.1, R8.2
unnamed: IC4.12 (IN+), R6.1, R7.2
unnamed: IC4.3 (IN+), R5.1, R6.2
unnamed: IC1.5 (IN+), R4.1, R5.2
unnamed: IC1.10 (IN+), R3.1, R4.2
unnamed: IC1.12 (IN+), R2.1, R3.2
unnamed: IC1.3 (IN+), R1.1, R2.2, SW1.2
unnamed: C1.1, C9.1, L1.1
unnamed: D8.2 (A), R10.2
unnamed: C8.1, L1.2, U1.1 (RFIN)
unnamed: D3.1 (K), IC1.8 (OUT)
unnamed: D4.1 (K), IC1.7 (OUT)
unnamed: D5.1 (K), IC4.1 (OUT)
unnamed: D6.1 (K), IC4.14 (OUT)
unnamed: D7.1 (K), IC4.8 (OUT)
unnamed: D8.1 (K), IC4.7 (OUT)
unnamed: D2.1 (K), IC1.14 (OUT)
unnamed: D1.1 (K), IC1.1 (OUT)
unnamed: D7.2 (A), R11.2
unnamed: D6.2 (A), R12.2
unnamed: D5.2 (A), R13.2
unnamed: D4.2 (A), R14.2
unnamed: D3.2 (A), R15.2
unnamed: D2.2 (A), R16.2
unnamed: D1.2 (A), R17.2
unnamed: BAT1.1 (POS), BAT1.2 (POS), SW2.2
unnamed: BAT1.- (NEG), BAT2.1 (POS), BAT2.2 (POS)
unnamed: R20.1, SW1.1
unnamed: C2.1, U1.4 (DECL)
unnamed: C2.2, R18.2
unnamed: C12.2, IC1.2 (IN-), IC1.6 (IN-), IC1.9 (IN-), IC1.13 (IN-), IC4.2 (IN-), IC4.6 (IN-), IC4.9 (IN-), IC4.13 (IN-), L2.2
unnamed: R9.1, R19.1, R19.3
unnamed: L2.1, U1.3 (VCAL)
unnamed: R21.1, U1.14 (ENBL)
unnamed: R22.2, R23.2, U1.16 (VIN-)
unnamed: TP3.TP, U1.12 (Q+)
VDD: C3.2, IC1.4 (V+), IC4.4 (V+), R1.2, R10.1, R11.1, R12.1, R13.1, R14.1, R15.1, R16.1, R17.1, R20.2, TP2.TP, U3.1 (VO)
VEE: C7.2, C10.1, SW2.1, U2.8 (VIN), U3.8 (VIN)

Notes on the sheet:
ADL5910
SMA
2 piles bouton
Bargraph
Gain
~750mV
0~470mV
Zero
GAIN
~770mV
~815mV
~840mV
~900mV
~960mV
~1030mV
LOOP
General purpose HF filter
Monitor Output/External EH Input

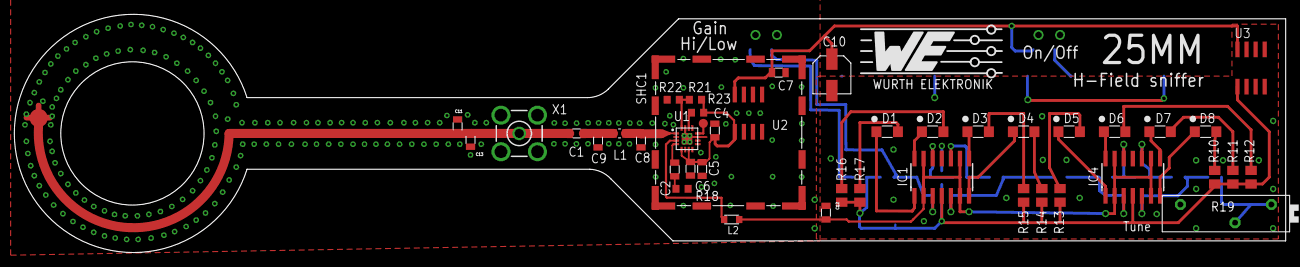
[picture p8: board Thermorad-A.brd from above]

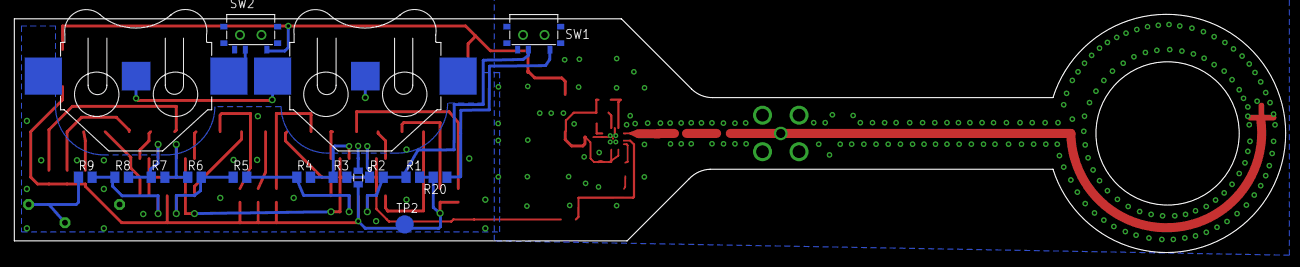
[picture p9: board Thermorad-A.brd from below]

Board: 2 copper layers, 177.5 x 33.3 mm, 60 parts (16 on the bottom side), 41 nets.

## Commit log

2019-03-21 Eagle source files
    [Thermorad-A.brd, Thermorad-A.sch]
2023-10-18 Update C
    [Rev-A.csv, Thermorad-A.brd, Thermorad-A.sch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]
2023-10-18 Update C - Cheaper Potentiometer implanted
    [BOM-Thermorad-C.xlsx, Thermorad-C.brd, Thermorad-C.sch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]
2023-10-19 Update BOM with partnumber and DNP
    [BOM-Thermorad-C-19-10-2023.xlsx, BOM-Thermorad-C.xlsx]

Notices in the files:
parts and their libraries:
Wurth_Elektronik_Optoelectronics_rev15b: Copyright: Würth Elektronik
